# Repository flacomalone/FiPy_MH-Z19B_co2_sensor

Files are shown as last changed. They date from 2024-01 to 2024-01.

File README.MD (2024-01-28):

AUTHOR: DAVID TENA GAGO

# IoT CO2 sensor for indoor air quality control

This repository contains the code (micropython) the FiPy firmware and the designs of the 3d printed case for the development of an indoors IoT-based CO2 concentration monitoring tool.   

the code than should be flashed into the fipy (or any other ESP32 dev board), is the content of the directory ``src/``. The rest should not be uploaded.

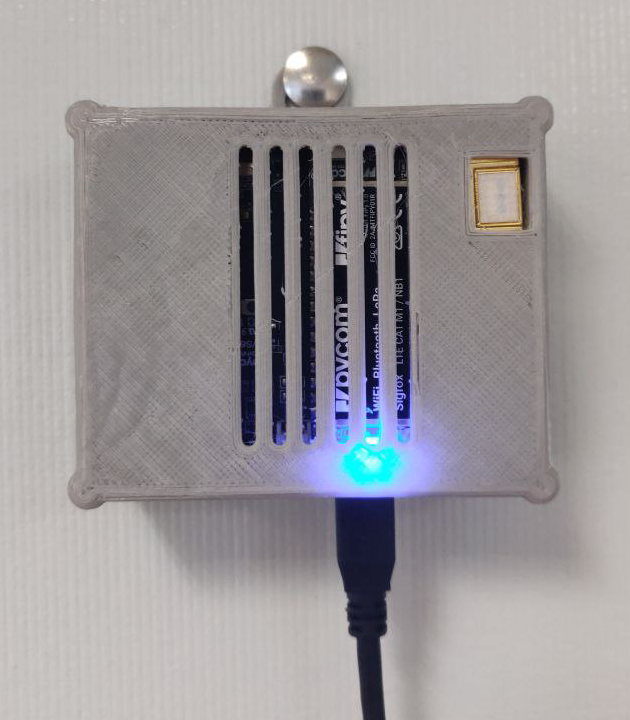
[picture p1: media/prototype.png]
prototype

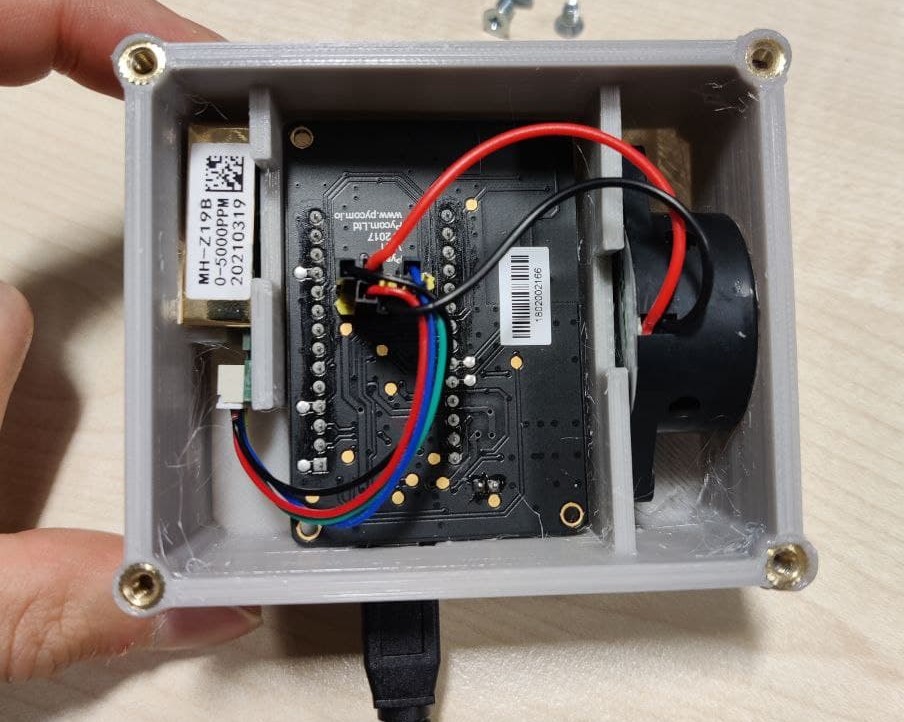
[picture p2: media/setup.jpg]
setup


## Usage (version 1.0):

### Opearation mode
Turn the device on by plugging it. By default, the sensor will start measuring in the normal operation mode after 2 beeps to indicate the start up. After the noise signal, a blue heartbeat will come from the FiPy LED. When a higher CO2 concentration is reached (800 by default),
the LED will turn red constantly, and a one beep will sound. When the concentration is lower than the threshold again, the sensor will come back to the blue heartbeat.

Normally, after the initial start up, a constant orange LED will indicate that there are lecture errors. It should change after a few seconds.

### Calibration
To calibrate the sensor you have to press once the PySense button (reachable through the front hole stripes). If pressed, the default calibration mode (zero level) will start. This will be indicated by a constant green light and 3 beeps. Ideally, the CO2 sensor should be placed somewhere with a 400 PPM concentration - outside or close to the window -. The calibration will finish when another beep indicates it, and will come back to the normal operation mode.

Another calibration method can be selected, which will consider the assumed CO2 concentration present in the environment where the sensor is being calibrated.

Also, the detection range can be selected. By default, the detection range is from 0 to 5000 PPM.

## Programming the FiPy
### UART
By default, the modules run an interactive python REPL on UART0 which is connected to P0 (RX) and P1 (TX) running at 115200 baud. The easiest way to connect to the FiPy is via our expansion board, but any USB UART adapter will suffice. Code can be run via this interactive REPL or you can use our PyMakr plugin for Atom or Visual Studio Code to upload code to the board.

### WiFi
By default, the FiPy also acts as a Wi–Fi access point SSID: fipy–wlan–XXXX with the password: www.pycom.io
Once connected to the FiPy’s Wi–Fi network you can access it in two ways:

#### Telnet
Running on port 23 is a telnet server. This acts in a very similar way to the UART. It presents you with an interactive REPL and can also be used to upload code via PyMakr

#### FTP
The FiPy also runs an FTP server that allows you to copy files to and from the device, include an SD card if one is connected. To connect to this FTP server, you need to use plain FTP (un–encrypted) with the following credentials:
* User: micro
* Password: python

## Boot modes
If powering up normally or upon pressing the reset button, a Pycom module will boot into standard mode; the boot.py file will be executed first, followed by main.py. It is possible to alter the boot procedure of the module by tying certain pins high or low when the module boots.
### Bootloader mode
In order to update the firmware of the FiPy device, it needs to be placed into bootloader mode. In order to do this, P2 (user button placed in the board that is connected to the FiPy) needs to be connected to ground when the device reboots. Once in bootloader mode you can use the Pycom firmware update tool to update to the latest official firmware. If you are developing your own firmware based on our open–source firmware, a flashing script is provided with the source code. This is not required if you are updating your MicroPython code.

### Safe boot mode
Sometimes the code you have written will prevent you gaining access to the REPL or prevent you updating your code. The micropython firmware features a safe boot feature that skips the boot.py and main.py scripts and goes straight to the REPL. To access this mode, you need to
connect P12 to 3.3V and reset the device. Upon entering safe boot mode, the on–board LED will begin to blink orange. Depending on the duration the pin is held at 3.3V, a different firmware will be run.
* 1 to 3 seconds: Current firmware without running boot.py or main.py
* 4 to 6 seconds: Previous firmware if the firmware was uploaded via OTA (without running boot.py and main.py)
* 7 to 9 seconds: Factory firmware is selected. 

## Hardware breakdown:
- Fipy: version 1.0
- Pysense (not version 2.0 X)
- CO2 sensor: MH-Z19B
- Buzzer: [SFM-27 DC 3-24V](https://www.amazon.co.uk/Electronic-Buzzer-Sounder-Continuous-Decibel/dp/B08TTFP58F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)

## Connections pinout
Acocording to FiPy documentation, the "user button" located in the PySense board is used to put the device in DFU-bootloader mode for firmware updates.

### MH-Z19B pinout
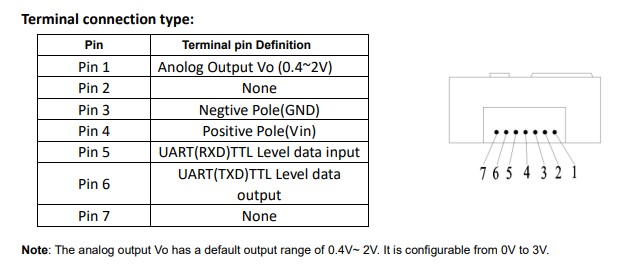
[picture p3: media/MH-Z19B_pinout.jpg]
MH-Z19B pinout

### Fipy pinout
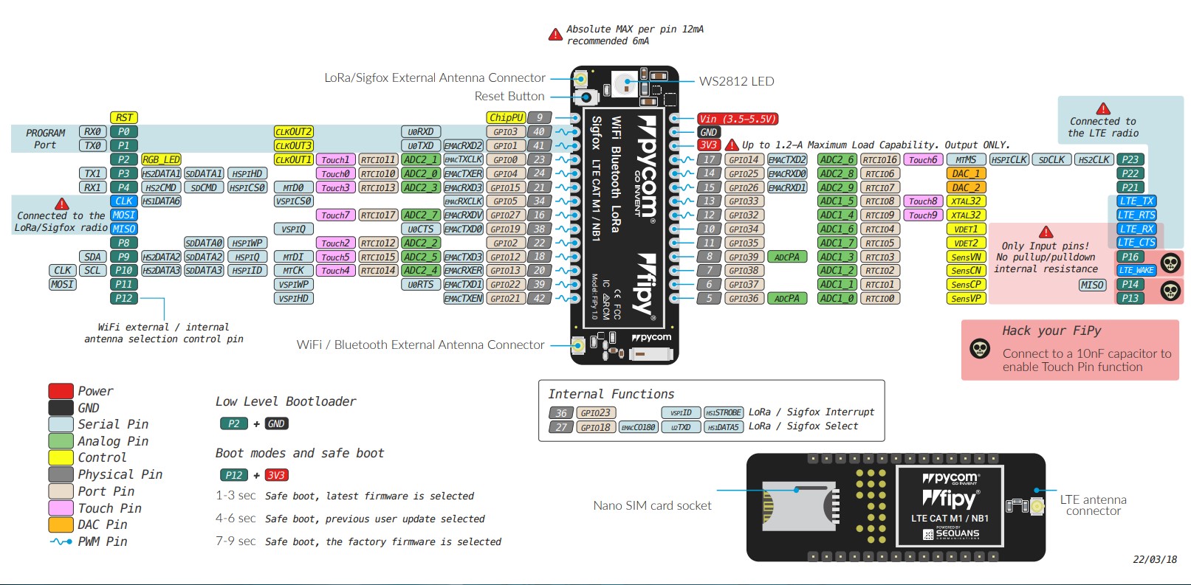
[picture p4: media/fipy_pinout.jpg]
Fipy pinoit

### Connection diagram
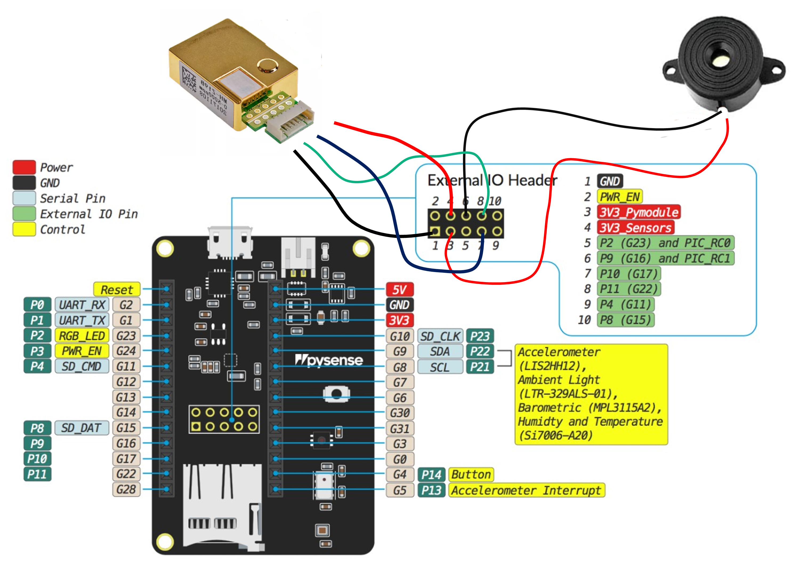
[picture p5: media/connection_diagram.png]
Connection diagram


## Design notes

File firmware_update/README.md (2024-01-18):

Steps for udpdating Fipy and Pysense firmware. It is important to follow these instructions in order.

**NOTE**: this guide was done for a Windows environment

# Pysense firmware update
1. Download the appropiate firmware file from [pycom webpage](https://docs.pycom.io/updatefirmware/expansionboard/). Version 0.0.8 is already in this repository.
2. Update the firmware. To do so:
     - Navigate to *firmware_update/dfu-utils* and have this command prepared to be run in your terminal:
            ```
            dfu-util-static.exe -D ..\pysense_0.0.8.dfu
            ```
    - Unplug the pysense
    - Remove any fipy if there is any
    - Press and hold the S1/MCLR button on your device (highlighted in red below)
    - Plug in the USB cable to the host computer and wait 1 second before releasing the button
    - After this you will have approximately 7 seconds to run the command described above
    
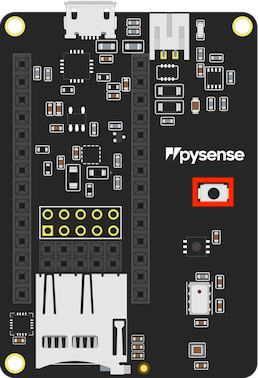
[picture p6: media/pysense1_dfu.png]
Pysense


If everything goes OK, you will have an output like this:
```text
dfu-util 0.9

Copyright 2005-2009 Weston Schmidt, Harald Welte and OpenMoko Inc.
Copyright 2010-2016 Tormod Volden and Stefan Schmidt
This program is Free Software and has ABSOLUTELY NO WARRANTY
Please report bugs to http://sourceforge.net/p/dfu-util/tickets/

Match vendor ID from file: 04d8
Match product ID from file: f014
Opening DFU capable USB device...
ID 04d8:f014
Run-time device DFU version 0100
Claiming USB DFU Runtime Interface...
Determining device status: state = dfuIDLE, status = 0
dfu-util: WARNING: Runtime device already in DFU state ?!?
Claiming USB DFU Interface...
Setting Alternate Setting #0 ...
Determining device status: state = dfuIDLE, status = 0
dfuIDLE, continuing
DFU mode device DFU version 0100
Device returned transfer size 64
Copying data from PC to DFU device
Download    [=========================] 100%        16384 bytes
Download done.
state(2) = dfuIDLE, status(0) = No error condition is present
Done!
```

if not, try again. 🤷‍

# Fipy firmware update

**IMPORTANT**: Make sure to update your Pysense/Pytrack/Expansion board accordingly before.

1. Install the Pycom Firmware Updater program. Installable file can be found in *firmware_update/pycom_firmware_updater_1.16.5.exe*
2. Open the program just installed
3. Insert your Fipy into a Pysense/Pytrack/Expansion board up-to-date.
4. Connect your board to the PC via USB.
5. Proceed with the seutup. Select options:

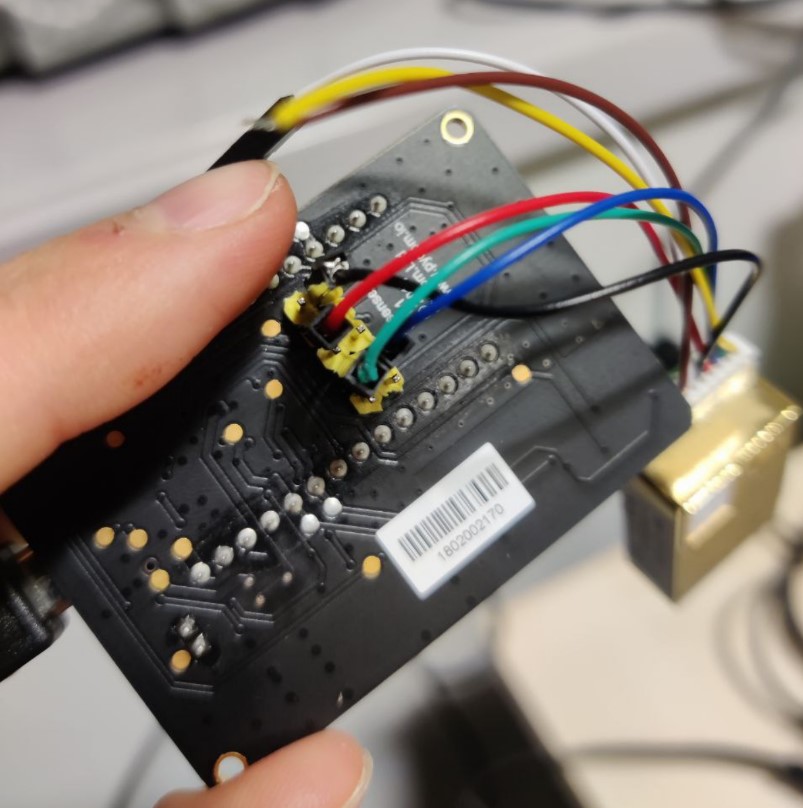
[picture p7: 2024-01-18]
media/connections.jpg

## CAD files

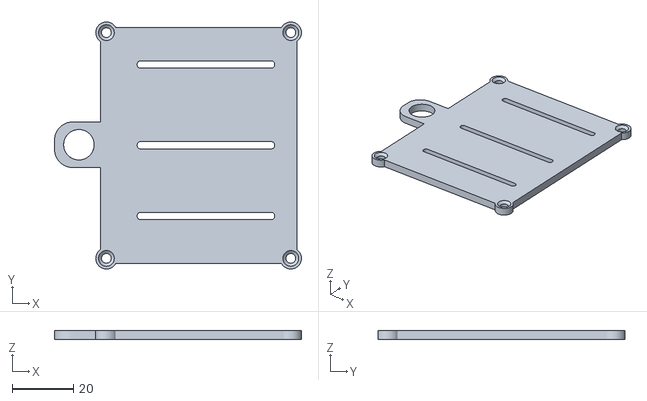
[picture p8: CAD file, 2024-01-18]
3D-printed-case/Part2.stl
81.0 x 81.0 x 3.00

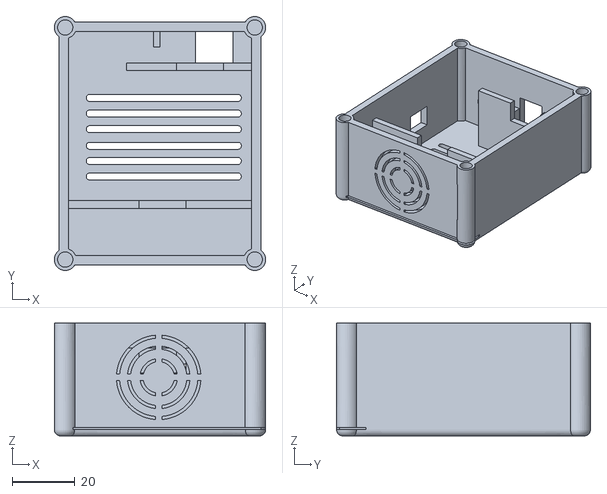
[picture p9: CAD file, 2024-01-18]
3D-printed-case/Part1.stl
67.5 x 81.0 x 36.0

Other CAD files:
3D-printed-case/Part1.ipt
3D-printed-case/Part2.ipt

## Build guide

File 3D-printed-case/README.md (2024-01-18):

The screws used to join the case with the back lid are M3 x 12 mm, and the brass nut used are M3 x 6 mm long. The ideal screw head is the Phillips flat countersunk.

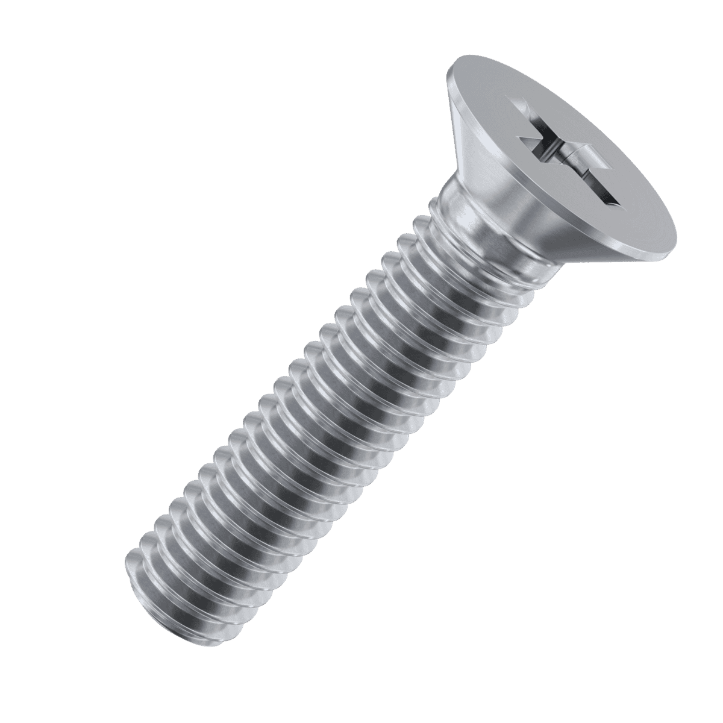
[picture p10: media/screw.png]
M3 Phillips countersunk screw

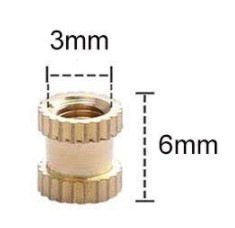
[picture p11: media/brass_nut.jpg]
M3 x 6 Thread Knurled Nuts Brass


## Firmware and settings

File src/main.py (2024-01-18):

import time
import pycom
import sys
import machine
import micropython
import ubinascii
import helpers.led_control as led_control
from helpers.colors import Colors
from machine import Timer

from network import WLAN

from button import Button
from machine import UART
from machine import Pin
from pysense import Pysense

#from mqtt import MQTTClient

from LIS2HH12 import LIS2HH12 # Accelerometer
from SI7006A20 import SI7006A20 # Temperature and humidity
from LTR329ALS01 import LTR329ALS01 # Ligth sensor
from MPL3115A2 import MPL3115A2,ALTITUDE,PRESSURE # barometer
from MH_Z19B import MH_Z19B # CO2 sensor
from buzzer import Buzzer


from machine import RTC

CONCENTRATION_THRESHOLD = 800 # PPM

def confgureAccessPoint():
    wlan = WLAN(mode=WLAN.AP, ssid="ROOM_E356", auth=(WLAN.WPA2, "CO2_B5GHUB")) # default IP is 192.168.4.1

def stablish_wifi_connection(ssid_=None, passwd= None):
    wlan = WLAN(mode=WLAN.STA)
    if not ssid_:
        ssid_ = "eduroam"
        wlan.connect(ssid=ssid_, auth=(WLAN.WPA2_ENT, "david.tena@uws.ac.uk", "DtenGag1998_UWS"), identity="david.tena@uws.ac.uk", timeout=100000)
    elif ssid_ is not None and passwd is not None:
        wlan.connect(ssid=ssid_, auth=(WLAN.WPA2, passwd), timeout=5000)
    else:
        print("ERROR: WiFi connection could not be stablished. SSID or Password were not given correctly")

    print("Attempting to create WiFi connection to SSID ", ssid_ ,"...")
    while not wlan.isconnected():
        machine.idle() # save power while waiting
    print('WLAN connection succeeded!. Connection information (IP, netmask, gateway, DNS):', wlan.ifconfig())
    led_control.blink(Colors.LED_WHITE)
    return wlan

def update_state(buzzer, co2_concentration, co2_limit_last_iter):
    limit_reached = co2_concentration >= CONCENTRATION_THRESHOLD

    if co2_concentration == -1: # CRC errors
        led_control.constant_orange()
        return -1
    else: # No CRC erros
        if co2_limit_last_iter == False and co2_concentration != -1: # First time no CRC errors
            led_control.blue_heartbeat()

        if limit_reached:
            if co2_limit_last_iter == False: # First time concentration limit is reached
                led_control.constant_red()
                buzzer.quick_beep()
            return True
        elif not limit_reached:
            if co2_limit_last_iter == True: # First time concentration is not reached
                led_control.blue_heartbeat()
            return False

def measure_co2(co2_sensor):
    return co2_sensor.read_co2()

def measure_temp_and_hum(temp_and_hum):
    return temp_and_hum.temperature(), temp_and_hum.humidity()

def measure_altitude(altitude):
    return altitude.altitude()

def measure_pressure(pressure):
    return pressure.pressure()

def measure_light(light):
    return light.light()

def measure_accelerometer(acc):
    return acc.acceleration(), acc.roll(), acc.pitch()

def calibrate_co2_sensor(buzzer, co2_sensor, span=None):
    buzzer.quick_beep(3)
    led_control.constant_green()

    if span is None:
        finish = co2_sensor.calibrate_zero_point()
    else:
        finish = co2_sensor.calibrate_span(span)
    while not finish:
        machine.idle()

    led_control.blue_heartbeat()
    buzzer.double_quick_beep()

def main(mode="online"):
    buzzer = Buzzer(Pin('P9', mode=Pin.OUT))
    co2_sensor = MH_Z19B(UART(1, 9600, bits=8, parity=None, stop=1,  pins=('P10','P11'))) # pins(TXD, RXD)
    button = Button()
    button.on()

    led_control.blue_heartbeat()

    # connect to WiFI network
    if mode == "online":
        wlan = stablish_wifi_connection(ssid_="RAMBOT_POST_LOVEYOU", passwd="28532538") # RAMBOT_POST_LOVEYOU password is 28532538
        #wlan = stablish_wifi_connection() # No connection configuration if connecting to eduroam

    # Create sensors
    py = Pysense()
    acc = LIS2HH12(py)
    temp_and_hum = SI7006A20(py)
    light = LTR329ALS01(py)
    altitude = MPL3115A2(py, mode=ALTITUDE)
    pressure = MPL3115A2(py, mode=PRESSURE)

    co2_limit_last_iter = False
    while True:
        if button.pressed == True:
            calibrate_co2_sensor(buzzer, co2_sensor)
            button.pressed = False
        else:
            co2_limit_last_iter = iterate(buzzer, co2_sensor, acc, temp_and_hum, light, altitude, pressure, co2_limit_last_iter)
        time.sleep(10)

def iterate(buzzer, co2_sensor, acc, temp_and_hum, light, altitude, pressure, co2_limit_last_iter, print_results=True):
    val_co2_concentration = measure_co2(co2_sensor)
    val_temperature, val_rel_humidity = measure_temp_and_hum(temp_and_hum)
    val_altitude = measure_altitude(altitude)
    val_pressure = measure_pressure(pressure)
    val_light = measure_light(light)
    val_acceleration, val_roll, val_pitch  = measure_accelerometer(acc)

    if print_results:
        print(  "CO2 concentration: " + str(val_co2_concentration) + " PPM\n"
                "Temperature: " + str(val_temperature) + " degrees C\n" +
                "Relative humidity: " + str(val_rel_humidity) + " %\n" +
                "Altitude: " + str(val_altitude) + "  metres\n" +
                "Pressure: " + str(val_pressure) + " Pascals\n" +
                "Light (channel Blue lux, channel Red lux): " + str(val_light) + "\n" +
                "Acceleration: " + str(val_acceleration) + "\n" +
                "Roll: " + str(val_roll) + "\n" +
                "Pitch: " + str(val_pitch) +
                "\n----------------------------------------\n",
                end="\r")
    return update_state(buzzer, val_co2_concentration, co2_limit_last_iter)

if __name__ == '__main__':
    confgureAccessPoint()
    main(mode="offline")

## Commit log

2024-01-18 add elements
    [Part1.ipt, Part1.stl, Part2.ipt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]
2024-01-28 add prototype picture
